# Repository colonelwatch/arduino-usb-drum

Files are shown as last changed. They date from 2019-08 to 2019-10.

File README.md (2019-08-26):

# arduino-usb-drum

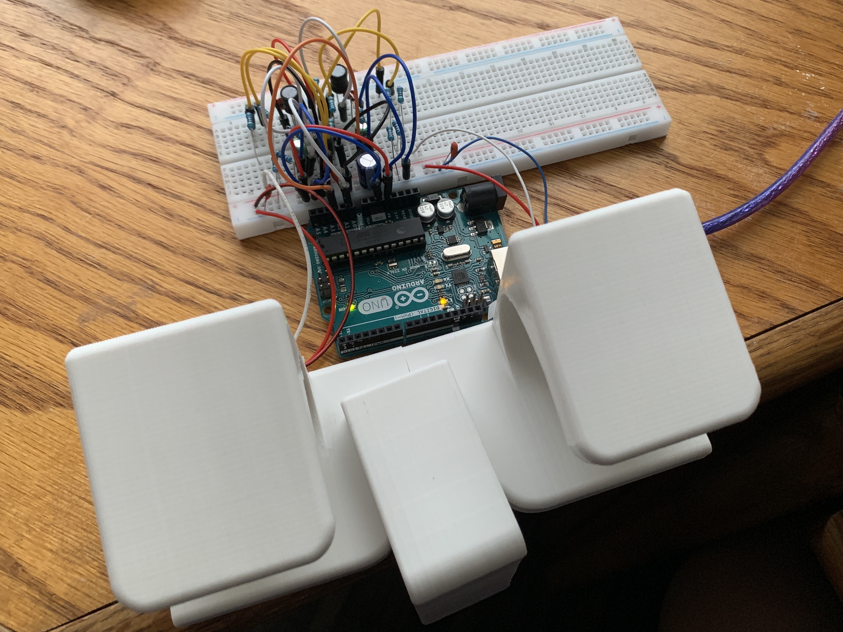
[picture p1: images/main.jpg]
Main Image


This project began as an experiment with strain guages which eventually became a drum. Here, using strain guages instead of the typical piezo sensor for drums enables more flexible design, such as making a 3d-printable model. It runs on an Arduino Uno, which has its serial interface turned into a MIDI input using [LoopMIDI](https://www.tobias-erichsen.de/software/loopmidi.html) and [Hairless MIDI](https://projectgus.github.io/hairless-midiserial/) running on the computer, and feeds into Ableton Live. Everything required to recreate this project is provided, but the code requires calibration due to variability in construction. 

## Explanation

The "drum" is 3D printed with three functional sections: the base, the stem, and the face-plate. The base is clamped to a table, and while one taps out a rhythm on the face-plate, that force causes the stem to bend. That bending can be measured by the strain guages configured in a half bridge which is directly hooked into a differential amplifier. This signal is then fed into a simple peak detector in order to make a response curve that's easy to program for.

The program basically works like this:

1. Because each input is bound to have a varied level of DC bias, the average of twenty samples is taken from each, which is subtracted from all future samples to compensate.
    * Because the circuit is prone to some noise, anything that falls in a certain range is eliminated and replaced with a zero.
2. All samples are fed into what is, in effect, a circular buffer with a size of ten, which the newest sample is compared against to determine if there has been a hit. This is set up for each input.
3. Once a hit has been determined for a certain input, the Arduino continually polls that input to determine a maximum value for a specific amount of time.
4. The maximum value is mapped within the MIDI specification then sent over serial, along with whatever note number that input is assigned and the NOTE_ON header.

## Components

The following are required per drum:
 - 3D-printed model
 - Strain guages (2) with lead wires
 - LM358 (1 per two inputs) and 0.1uF capacitor
 - 1N4148, or any standard diode
 - 10mH inductor, or a 10k resistor
 - 100 resistor (2)
 - 10k resistor (3)
 - 100k resisitor (2)
 - 0.1uF capacitor (2)
 - 10uF capacitor
The following are required regardless of drum count:
 - Arduino Uno
 - 1000uF capacitor

## Schematic

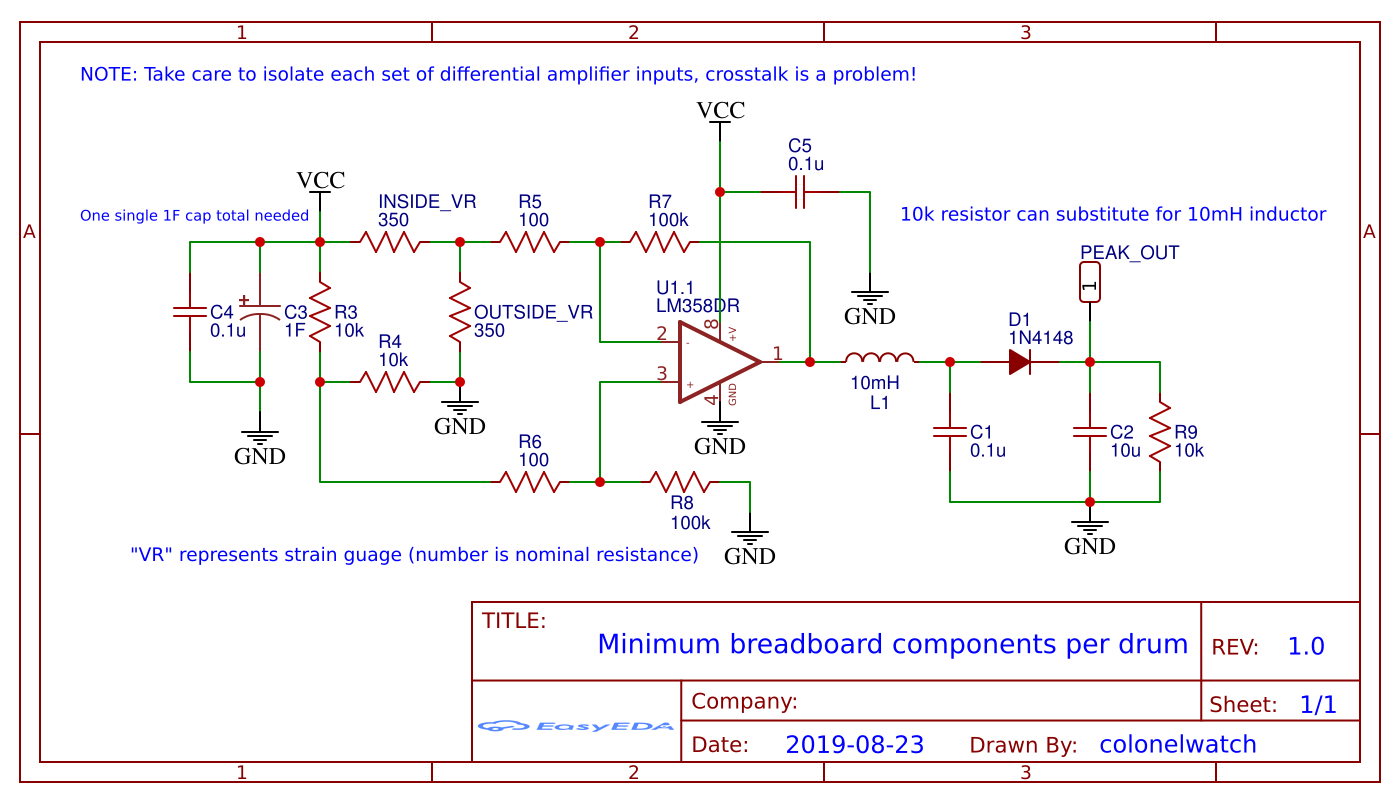
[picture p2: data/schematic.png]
Schematic


## Demonstration

arduino-usb-drum demonstration (https://www.youtube.com/watch?v=Jy1ZnwRxwZo)

## TO-DO

 - Port program to the Arduino Pro Micro, which can be configured as a class-compliant USB MIDI device (or attempt to figure out V-USB or the micronucleus bootloader, which can be configured to do the same)
 - Eliminate peak detector with further programming
 - Go from half-bridge to quarter-bridge if possible
 - Update code to be more flexible with drums count up to six
 - Migrate from breadboard to PCB or perfboard to mitigate possible crosstalk

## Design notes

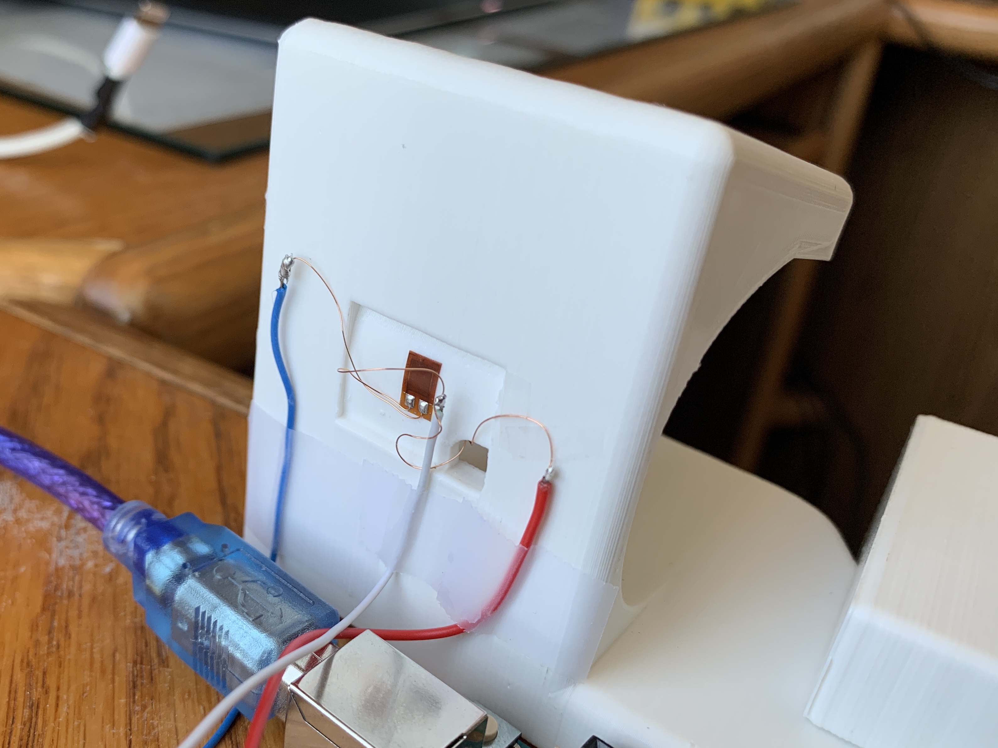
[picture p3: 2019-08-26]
images/drum back.JPG

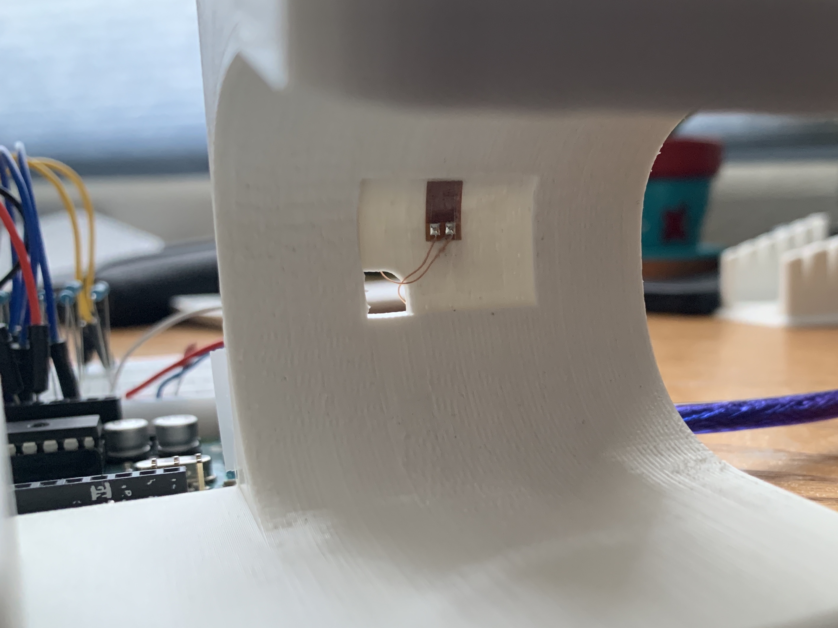
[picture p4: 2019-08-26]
images/drum front.JPG

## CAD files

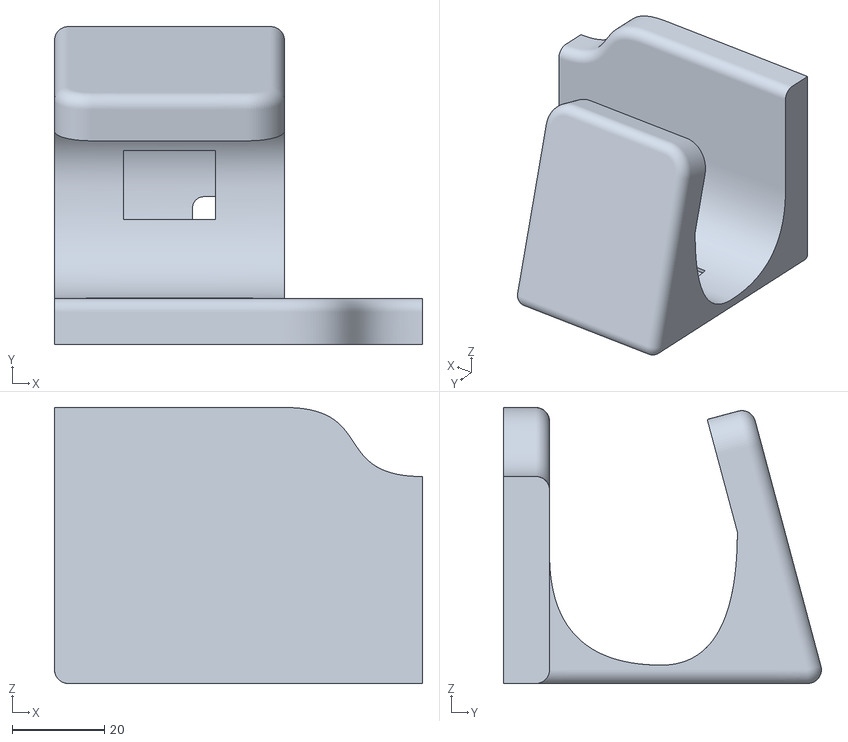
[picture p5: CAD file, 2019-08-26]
data/Finger Drums.stl
80.0 x 69.1 x 60.0

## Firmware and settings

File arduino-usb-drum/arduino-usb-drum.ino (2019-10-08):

// User configurable values
#define DEAD_RANGE 2        // minimum deviation from zero point, combats noise (increase to raise cutoff)
#define DEBOUNCE_TIME 50000 // in microseconds, minimum time between notes to eliminate notes caused by ringing
#define MIDI_NOTE 60        // MIDI note number, ranges from 0 - 127
// MUST be configured by the user
#define DRUM_ONE_MAX 80     // Maximum height measured by drum one, found using calibration sketch
#define DRUM_TWO_MAX 200    // Maximum height measured by drum two, found using calibration sketch

// Global constants
const int sensitivity1 = DRUM_ONE_MAX / 10.;
const int sensitivity2 = DRUM_TWO_MAX / 10.;

// Global variables
int avg, avg2;                                              // Stores value of DC bias
unsigned long hit_timestamp, hit_timestamp2;                // Stores time of hit for debouncing purposes
int buff[10] = {0}, buff2[10] = {0}, iBuff = 0, iBuff2 = 0; // Circular buffer of past samples and its index

void setup() {
  // put your setup code here, to run once:
  Serial.begin(115200);         // Opens serial link with computer for Hairless MIDI to grab (Note: set baud rate in Hairless to 115200)
  
  // Initializes peak detector input pins
  pinMode(A0, INPUT);
  pinMode(A2, INPUT);

  // Throws out initial 20 values before finding average
  for(int i = 0; i < 20; i++){
    analogRead(A0);
    analogRead(A2);
  }

  // Finds average value in order to compensate for DC bias later
  int total = 0, total2 = 0, deriv_total2 = 0;
  for(int i = 0; i < 20; i++){
    total += analogRead(A0);
    total2 += analogRead(A2);
  }
  avg = total/20;
  avg2 = total2/20;

  // Fills buffer before first loop
  hit_timestamp = micros();
  hit_timestamp2 = micros();
  buff[iBuff] = analogRead(A0) - avg;
  iBuff++;
  buff2[iBuff2] = analogRead(A2) - avg2;
  iBuff2++;
  delay(10);
}

void loop() {
  // put your main code here, to run repeatedly:
  int pulse_max2 = 0;    // Stores maximum value of pulse
  
  // Reads from each input while compensating for DC bias
  int val = analogRead(A0) - avg;
  if(abs(val) <= DEAD_RANGE) val = 0;
  int val2 = analogRead(A2) - avg2;
  if(abs(val2) <= DEAD_RANGE) val2 = 0;
  
  // Checks if greatest change is greater than trigger value
  bool trigger = false;
  for(int i = 0; i < 10; i++) if(val > buff[i] + sensitivity1) trigger = true;
  bool trigger2 = false;
  for(int i = 0; i < 10; i++) if(val2 > buff2[i] + sensitivity2) trigger2 = true;

  // Finds peak then sends MIDI note
  if(trigger && micros() > hit_timestamp + DEBOUNCE_TIME){
    int pulse_max = 0;    // Stores maximum value of pulse
    hit_timestamp = micros();
    while(val > buff[iBuff] - DEAD_RANGE){   // Holds uC in recording stage until measured value starts to fall
      val = analogRead(A0) - avg;
      if(abs(val) <= DEAD_RANGE) val = 0;
      if(val > pulse_max) pulse_max = val;    // Raises maximum value if it is exceeded
      
      // Adds reading to buffer 1
      if(iBuff < 10){
        buff[iBuff] = val;
        iBuff++;
      }
      else{
        iBuff = 0;
        buff[iBuff] = val;
      }
    }
    if(pulse_max > DRUM_ONE_MAX) pulse_max = DRUM_ONE_MAX;  // Caps maximum value to prevent overflow

    // MIDI output to Serial
    Serial.write(0b10010000);                             // Sends inital NOTEON byte in MIDI
    Serial.write(MIDI_NOTE);                              // Sends user-defined MIDI note
    Serial.write(map(pulse_max, 0, 80, 20, 127));         // Maps maximum value to note velocity then sends
  }
  else{
    // Adds reading to buffer 1
    if(iBuff < 10){
      buff[iBuff] = val;
      iBuff++;
    }
    else{
      iBuff = 0;
      buff[iBuff] = val;
    }
  }

  // Same as above, but with different variables for drum 2
  if(trigger2 && micros() > hit_timestamp2 + DEBOUNCE_TIME){
    int pulse_max = 0;
    hit_timestamp2 = micros();
    while(val2 > buff2[iBuff2] - DEAD_RANGE){
      val2 = analogRead(A2) - avg2;
      if(abs(val2) <= DEAD_RANGE) val2 = 0;
      if(val2 > pulse_max) pulse_max = val2;
      
      // Adds reading to buffer 2
      if(iBuff2 < 10){
        buff2[iBuff2] = val2;
        iBuff2++;
      }
      else{
        iBuff2 = 0;
        buff2[iBuff2] = val2;
      }
    }
    if(pulse_max > DRUM_TWO_MAX) pulse_max = DRUM_TWO_MAX;
    Serial.write(0b10010000);
    Serial.write(MIDI_NOTE+1);
    Serial.write(map(pulse_max, 0, 200, 20, 127));
  }
  else{
    // Adds reading to buffer 2
    if(iBuff2 < 10){
      buff2[iBuff2] = val2;
      iBuff2++;
    }
    else{
      iBuff2 = 0;
      buff2[iBuff2] = val2;
    }
  }
}

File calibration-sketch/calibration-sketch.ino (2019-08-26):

void setup() {
  // put your setup code here, to run once:
  pinMode(A0,INPUT);
  pinMode(A2,INPUT);
  Serial.begin(115200);
}

void loop() {
  // How to calibrate: (1) Record the value after it settles with no pressure, (2) hold the plates down with modest pressure, then (3) record the new value
  //                   The difference is what should be entered for DRUM_###_MAX
  Serial.print(analogRead(A0));   // Drum one
  Serial.print(' ');
  Serial.println(analogRead(A2)); // Drum two
}
